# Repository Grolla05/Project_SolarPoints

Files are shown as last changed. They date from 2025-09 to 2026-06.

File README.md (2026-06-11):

# 💡 Project Solar Points — Smart Lighting for Low-Infrastructure Areas

> Light where there’s no infrastructure. Safety through simplicity and efficiency.



---

## 🌙 O que é o Solar Points?

O **Solar Points** é um sistema de iluminação pública autônomo e inteligente pensado para locais com pouca ou nenhuma infraestrutura elétrica, como:

- Paradas de ônibus
- Vielas e ruas estreitas
- Praças públicas
- Regiões periféricas e isoladas
- Áreas externas de residências

O objetivo permanece o mesmo: aumentar a segurança e o bem-estar comunitário com uma solução de baixo custo, sustentável e de fácil manutenção.

---

## 🔁 Evolução do projeto: de totalmente analógico para arquitetura digital

Inicialmente o projeto foi concebido como **100% analógico** (apenas componentes discretos e circuitos analógicos). Com as necessidades de sensoriamento mais preciso, flexibilidade operacional e otimização de consumo, o projeto evoluiu para uma **arquitetura digital/híbrida** baseada em microcontrolador e periféricos.

Essa mudança preserva os princípios de simplicidade, robustez e baixo consumo, ao mesmo tempo que agrega capacidades importantes:

- **Leitura digital de sensores** (intensidade de luz, distância/presença)
- **Decisões e temporizações programáveis** via firmware leve
- **Gerenciamento inteligente de energia** (controle de conversores DC-DC, modos de sono)
- **Comunicação entre módulos** via I2C/GPIO quando necessário

> A imagem anexada ao repositório ilustra o bloco funcional do novo design: microcontrolador central, sensores de luz e distância, gerenciamento de energia, baterias e conversores DC-DC.

---

## ⚙️ Principais funcionalidades (atualizado)

- **Ativação automática** baseada em sensores de luminosidade e presença
- **Modos ajustáveis** via firmware (p.ex. sensibilidades, temporização)
- **Operação autônoma** com painéis solares e baterias
- **Gestão adequada de energia** com conversores DC-DC e técnicas de baixo consumo
- **Projeto modular e replicável** com possibilidade de atualização de firmware

---

## 🛠️ Tecnologias e componentes (atualizado)

- **Microcontrolador** (unidade central de controle) — responsável por leitura de sensores e lógica de acionamento
- **Sensor de luminosidade** (LDR/photodiode + ADC) — medida de intensidade luminosa
- **Sensor de distância/presença** (ultrassom/IR) — detectar passagem ou presença
- **Conversores DC-DC** (step-up/step-down) — fornecimento estável para LEDs e eletrônica
- **Gestão de energia / Power Management** (monitoramento de bateria, carregamento solar)
- **Bateria recarregável e painéis solares**
- **LEDs de potência** para iluminação pública
- **Interfaces**: GPIOs para sinalização/controle, I2C para sensores/power ICs quando aplicável

---

## 🔍 Diagrama funcional

O diagrama no repositório mostra os blocos principais interconectados:

- 1 — Baterias (alimentação)
- 4 — Power Management (monitoramento/carregador)
- 11 — Conversão DC-DC (alimentação dos LEDs e eletrônica)
- 2 — Microcontrolador (núcleo lógico)
- 5 — Medição de intensidade luminosa (sensor)
- 6 — Sensor de distância/presença
- 3 — LED de status / power

O microcontrolador realiza a lógica central: lê sensores (GPIOs/ADC/I2C), decide quando ligar os LEDs e controla os conversores para otimizar consumo.

---

## ✨ Aplicações no mundo real

O Solar Points continua ideal para iluminar pontos sem infraestrutura elétrica: pontos de ônibus, caminhos em áreas rurais, entradas de condomínios e outras localidades onde uma solução autônoma e resiliente faz diferença.

---

## 👥 Autores

Desenvolvido por:

- **Felipe Grolla Freitas** – Engenharia de Controle e Automação (PUC-Campinas)
- **Guilherme Oliveira Nogueira** – Engenharia de Controle e Automação (PUC-Campinas)
- **Giovanna Lima Salvagnini** – Engenharia de Controle e Automação (PUC-Campinas)
- **Henrique Spadaccia Chambó** – Engenharia de Controle e Automação (PUC-Campinas)

---

> 🧠 "A simplicidade, aliada a decisões digitais pontuais, amplia o impacto das soluções de engenharia em contextos reais."

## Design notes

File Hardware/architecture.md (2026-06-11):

# Documentação de Hardware - Projeto de Iluminação Autônoma Solar

## Visão Geral do Projeto

Este projeto consiste em um sistema de iluminação autônoma e inteligente, projetado para operar com energia solar. Ele carrega uma bateria interna e acende uma lâmpada LED ao detectar movimento, mas apenas quando a luz ambiente estiver baixa. A arquitetura de hardware é dividida em blocos funcionais para garantir eficiência, segurança e robustez.

-----

## 1. Arquitetura do Circuito

O circuito é centrado em um chip de **Gerenciamento de Energia** (Power Management) que controla o fluxo entre as fontes de energia, a bateria e o sistema lógico. A principal característica do design é a separação entre o **circuito de controle de baixa tensão (5V)** e o **circuito de potência de alta tensão (12V)**, isolados por um Módulo Relé.

### Diagrama de Blocos do Circuito Completo

```
+------------------------------------------------------------------------------------------------------------------------------+
|                            Gerenciamento de Energia (Ex: BQ25881)                                                            |
|                                                                                                                              |
|   Entrada 12V (Vin) do Painel Solar        Saída ~12V (SYS) para o Sistema                                                   |
|              ▼                                            ▼                                                                  |
|       +------+--------------------------------------------+------------------------------------------------------------------+
|       |      |                                            |                                                                  |
|       |      | Carrega/Descarrega (BAT)                   |                                                                  |
|       |      |                                            |                                                                  |
|       ▼      ▼                                            ▼                                                                  |
|  +----------+----------+                        +-------------------------+                                                  |
|  |  Bateria 12V + BMS  |                        | Conversor DC-DC (5V)    |                                                  |
|  +---------------------+                        +-----------+-------------+                                                  |
|          ^                                                  |                                                                |
|          |                                                  | (Alimentação Lógica 5V e GND)                                  |
|          +--------------------------------------------------+-------------------------------+                                |
|                                                             |                               |                                |
|  (Circuito de Controle - 5V)                                ▼                               |                                |
|                                                  +--------------------+                     |                                |
|                     +----------------------------+  Microcontrolador  |                     |                                |
|                     |                            |      (ESP32)       |                     |                                |
|                     |                            +--+------+-------+--+                     |                                |
|                     |                               |      |       |                        |                                |
|                 Módulo GPS               (Sinal IN) |      |       | (Sinal OUT)            |                                |
|                                                     ▼      ▼       ▼                        |                                |
|                                                +----------+-+-+----------+       +-------------------+                       |
|                                                | Sensor PIR | |Sensor LDR|       | Módulo Relé 5V    |                       |
|                                                +------------+ +----------+       |                   |                       |
|                                                                                  | VCC | GND | IN    |                       |
|                                                                                  +--+----+-----------+                       |
|                                                                                  |  |    |                                   |
|                                                                                  |  |    |                                   |
| (Circuito de Potência - 12V, chaveado pelo Relé)                                 |  |    | (do pino GPIO)                    |
|                                                                                  |  |    |                                   |
|   +---------------------+                                                        |  +----+ (do GND)                          |
|   | Fonte de Energia    |                                                        +-------+ (do 5V)                           |
|   | (Bateria/SYS ~12V)  |                                                                |                                   |
|   +----------+----------+                                                                |                                   |
|              | (+)                                                                       |                                   |
|              |                                                                           |                                   |
|              +---------------------------------------------------------------------------+ (Terminal COM)                    |
|                                                                                             (Terminal NO)                    |
|                                                                                                   |                          |
|                                                                                                   | (+)                      |
|                                                                                                   ▼                          |
|                                                                                            +---------------+                 |
|                                                                                            | Lâmpada LED   |                 |
|                                                                                            |     12V       |                 |
|                                                                                            +-------+-------+                 |
|                                                                                                    | (-)                     |
|                                                                                                    ▼                         |
|                                                                                             (GND da Fonte 12V)               |
|                                                                                                                              |
+------------------------------------------------------------------------------------------------------------------------------+
```

-----

## 2. Seleção de Componentes e Justificativa

A escolha de cada componente foi pensada para garantir segurança, eficiência e funcionalidade.

* **Painel Solar (12V):** Fonte de energia primária. Sua tensão de 12V é ideal para carregar diretamente a bateria de 12V e alimentar o circuito lógico.
* **Bateria de Lítio (12V 3S):** Fornece energia para o sistema durante a noite. Uma bateria de 3 células em série (3S) tem tensão nominal de 11.1V, compatível com a fonte solar.
* **Módulo BMS (Battery Management System):** **Componente crítico para a segurança**. O BMS protege a bateria contra sobrecarga, sobredescarga e curtos-circuitos, além de realizar o balanceamento de células, prolongando a vida útil do pacote de baterias.
* **Chip de Gerenciamento de Energia (Ex: BQ25881):** O cérebro do sistema de energia. Este chip implementa a funcionalidade de ***power path***, direcionando a energia da fonte solar para a carga e, em seguida, para a bateria, de forma automática e eficiente.
* **Conversor DC-DC (Step-down):** Essencial para a eficiência. Ele recebe a tensão variável da saída do gerenciador de energia e a converte para uma tensão estável de 5V, ideal para o microcontrolador e os sensores. A alta eficiência minimiza a perda de energia em forma de calor.
* **Microcontrolador (ESP32):** O controlador lógico. O ESP32 foi escolhido por sua versatilidade, baixo consumo de energia e capacidade de processar dados dos sensores.
* **Sensor PIR (Infravermelho Passivo):** Sensor de movimento. Envia um sinal digital `HIGH` para o ESP32 quando detecta presença, ativando a rotina de acionamento da luz.
* **Sensor de Luz (LDR):** Sensor de luminosidade. Através de um divisor de tensão, ele fornece um sinal analógico ao ESP32, permitindo que o sistema determine se a luz ambiente é suficiente para ligar a lâmpada.
* **Módulo Relé 5V com Optoacoplador:** Atua como um interruptor eletrônico seguro. Permite que o ESP32, com um sinal de baixa potência (5V), controle uma carga de alta potência (a lâmpada de 12V). O **optoacoplador** é fundamental, pois isola eletricamente o microcontrolador do circuito de potência, protegendo-o de ruídos e picos de tensão gerados pelo acionamento do relé.

-----

## 3. Fluxo de Operação do Circuito

O sistema opera em um ciclo contínuo, com a energia e a lógica seguindo um fluxo bem definido:

1. **Gerenciamento de Energia:** A energia do painel solar entra no chip de gerenciamento (`Vin`), que a direciona para a saída `SYS` (para alimentar o sistema) e para a porta `BAT` (para carregar a bateria via BMS).

2. **Alimentação Lógica:** O conversor DC-DC recebe a energia da saída `SYS` e a regula para 5V, alimentando o **ESP32**, os sensores e o Módulo Relé de forma estável.

3. **Lógica Condicional:** O **ESP32** continuamente lê a saída dos dois sensores:
    * O sinal **digital** do **sensor PIR** (HIGH se houver movimento).
    * O sinal **analógico** do **sensor de luz**.

4. **Acionamento da Lâmpada:** O **ESP32** só envia um sinal de ativação para o Módulo Relé se **ambas** as condições forem verdadeiras:
    * `(1)` **Há movimento detectado** (sinal PIR = HIGH).
    * `(2)` **A luz ambiente é insuficiente** (o valor analógico do sensor de luz está acima de um limite programado).

5. **Controle via Relé:** Se as condições forem atendidas, o **ESP32** envia um sinal digital `HIGH` para o Módulo Relé. O relé então atua como um interruptor, fechando o circuito de 12V e acendendo a Lâmpada LED em sua potência máxima. Quando as condições não são mais atendidas, um sinal `LOW` é enviado, abrindo o circuito e desligando a lâmpada.

-----

## 4\. Lista de Materiais

* Painel Solar 12V
* Bateria de Lítio (3S, 12V)
* <a href="https://www.handsontec.com/dataspecs/module/3S-10A-18650-Charger.pdf">Módulo BMS 3S</a>
* <a href="https://www.ti.com/lit/ug/sluuc12/sluuc12.pdf?ts=1757377702366">Chip de Gerenciamento de Bateria com ***Power Path*** (ex: BQ25881)</a>
* Conversor DC-DC Step-down (para 5V)
* <a href="https://www.espressif.com/sites/default/files/documentation/esp32_datasheet_en.pdf">**Microcontrolador ESP32**</a>
* <a href="https://www.handsontec.com/dataspecs/SR501%20Motion%20Sensor.pdf">Sensor de Movimento PIR (HC-SR501)</a>
* <a href="https://components101.com/sites/default/files/component_datasheet/LDR%20Datasheet.pdf">Sensor de Luz (LDR)</a>
* <a href="https://www.eletruscomp.com.br/arquivos/1488539846_dados_tecnicos_p9___gbk_rele_10a_simples.pdf">Relay</a>
* Lampada LED
* <a href="https://content.u-blox.com/sites/default/files/products/documents/NEO-6_DataSheet_%28GPS.G6-HW-09005%29.pdf">Módulo GPS (NEO-6)</a>
* Resistores: 10kΩ, 1kΩ e 220Ω (ou 330Ω)

-----

## 5\. Esquemas e Layouts do Projeto

Esta seção é dedicada à documentação visual do projeto, fundamental para a construção e replicação.

### Diagrama Esquemático

* [Insira aqui a imagem do seu diagrama esquemático, mostrando as conexões de todos os componentes.]

### Layout da Placa de Circuito Impresso (PCB)

* [Insira aqui a imagem do layout da sua PCB, com as trilhas, componentes e silkscreen.]

### Imagens do Protótipo ou Produto Final

* [Insira aqui as fotos do seu projeto montado na protoboard ou na PCB final.]

-----

## 6\. Desenvolvedores do Projeto

**Felipe Grolla Freitas** – Engenharia de Controle e Automação (PUC-Campinas)<br>
**Guilherme Oliveira Nogueira** – Engenharia de Controle e Automação (PUC-Campinas)<br>
**Giovanna Lima Salvagnini** – Engenharia de Controle e Automação (PUC-Campinas)<br>
**Henrique Spadaccia Chambó** – Engenharia de Controle e Automação (PUC-Campinas)

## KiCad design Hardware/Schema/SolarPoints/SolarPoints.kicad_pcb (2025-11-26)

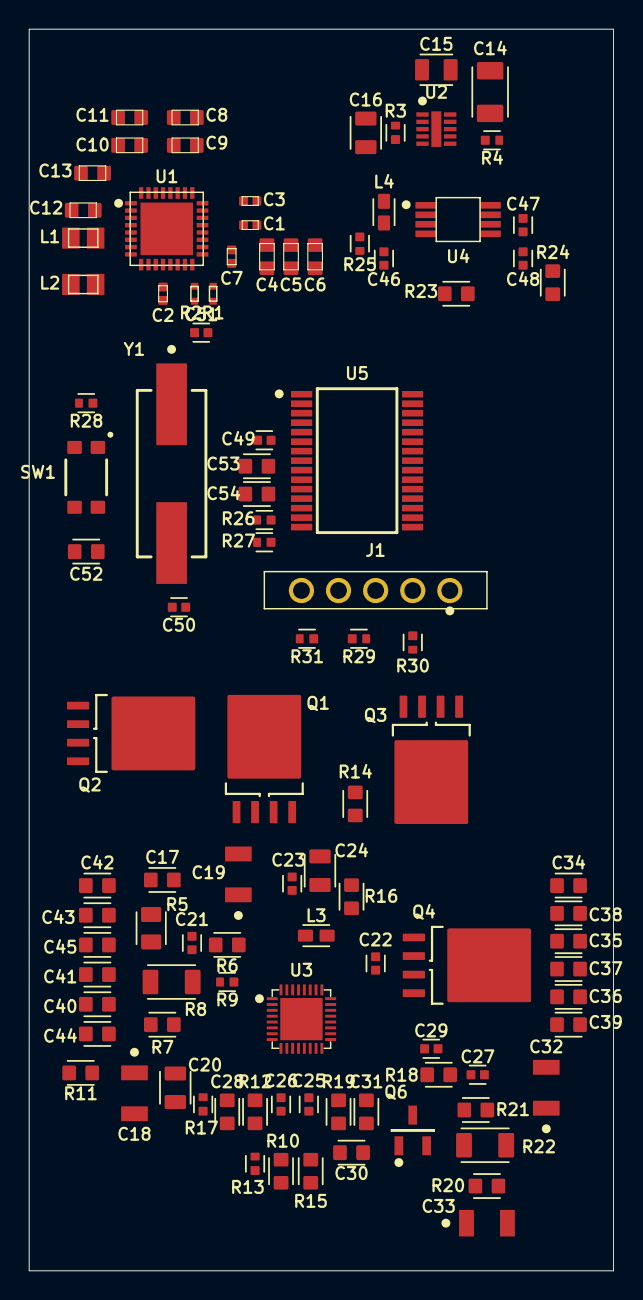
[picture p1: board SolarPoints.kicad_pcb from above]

Board: 0 copper layers, 40.0 x 85.0 mm, 102 parts (0 on the bottom side), 63 nets, no tracks yet.

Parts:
C1, C3: 04023D105KAT2A
C2: KGM05CR71H104KH
C4, C5, C6, C8, C9, C10, C11, C12, C13: GRM188Z71A106KA73D
C7: GRM155Z71A225KE01D
C14: 12061C105K4Z4A
C15: 08051C104KAT2A
C16, C20: 08051C474K4Z2A
C17, C28: CL10A105KL8NNNC
C18, C19, C32, C33: C1206C153J5GACTU
C21: GRM155R71E103KA01D
C22, C23: GRM155R71H473KE14J
C24: C0805C225K5RACTU
C25, C26: CL05C101JB51PND
C27: CL05B681KB5VPNC
C29: CC0402JRNPO9BN150
C30: CL10C182JB8NNNC
C31: GRM1885C1H330JA01D
C34, C35, C36, C37, C38, C39, C40, C41, C42, C43, C44, C45: CL10A106MA8NRNC
C46, C48: GRM155R60J106ME15D
C47: GRM158R61A226ME15D
C49: CL05A105KO5NNNC
C50, C51: C0402C180J5GACTU
C52, C53, C54: 06035C104K4T2A
J1: 61300511021
L1, L2: MLZ2012M2R2HT000
L3, L4: LQM18PN2R2MFRL
Q1, Q2, Q3, Q4: SIJA72ADP-T1-GE3
Q6: SI2319DS-T1-E3
R1: ERJ2RKF4702X
R2: ERJ2RKF1503X
R3: ERJ2BSFR10X
R4: ERJ2RKF2001X
R5: CRCW08052R20FKEA
R6, R7, R16, R20, R21: RC0603FR-0710RL
R8, R22: ERJ8CWFR010V
R9: ERJ2GEJ1R0X
R10: ERJ3EKF3002V
R11: ERJ3EKF1003V
R12: RT0603FRE13330KL
R13, R17: ERJ2RKF2203X
R14: ERJ3GEYJ103V
R15: RT0603BRE0750RL
R18: ERJ3EKF1002V
R19: ERJS03F4022V
R23: ERJPA3F1003V
R24: ERJ3EKF7503V
R25: ERA2AED472X
R26, R27, R28: MCS0402MC1002FE000
R29, R30, R31: ERJ2RKF1001X
SW1: KMR221GLFS
U1: NPM1300-QEAA-R
U2: LTC2959IDDB#TRMPBF
U3: BQ25708RSNR
U4: PAM2401SCADJ
U5: R5F102AAASP#50
Y1: ABLS-20.000MHZ-B-2-T

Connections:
/GPIO4: R14.1, U1.11, U3.4
/sheet_1_Power Management/VBUSOUT: C3.1, U1.22
/sheet_2_Batteries/GPIO: R4.1, U2.8
/sheet_3_Battery Managemen.../ACN: C19.1, R6.1, U3.2
/sheet_3_Battery Managemen.../ACP: C18.1, R7.1, U3.3
/sheet_3_Battery Managemen.../BATDRV: Q6.1, U3.21
/sheet_3_Battery Managemen.../HIDRV1: Q1.4, U3.31
/sheet_3_Battery Managemen.../HIDRV2: Q4.4, U3.24
/sheet_3_Battery Managemen.../LODRV1: Q2.4, U3.29
/sheet_3_Battery Managemen.../LODRV2: Q3.4, U3.26
/sheet_3_Battery Managemen.../N$1_1: C28.1, R17.2, U3.6
/sheet_3_Battery Managemen.../PROCHOT: R15.2, U3.11
/sheet_3_Battery Managemen.../REGN: C24.1, R16.1, U3.28
/sheet_3_Battery Managemen.../SRN: C33.1, R20.1, U3.19
/sheet_3_Battery Managemen.../SRP: C32.1, R21.1, U3.20
/sheet_3_Battery Managemen.../SW1: C23.1, L3.1, Q1.1, Q1.2, Q1.3, Q2.5, U3.32
/sheet_3_Battery Managemen.../SW2: C22.2, L3.2, Q3.5, Q4.1, Q4.2, Q4.3, U3.23
/sheet_3_Battery Managemen.../VBUS: C20.1, R9.1, U3.1
/sheet_3_Battery Managemen.../VDDA: R12.2, R16.2, U3.7
/sheet_4_Switching DC-DC C.../EN: R25.1, U4.2
/sheet_5_Microcontroller/RESET: C52.1, J1.4, R28.1, R29.1, R31.1, SW1.1, SW1.4, U5.6
/sheet_5_Microcontroller/SCL: R26.1, U5.13
/sheet_5_Microcontroller/SDA: R27.1, U5.14
/sheet_5_Microcontroller/TOOL0: J1.2, R30.1, U5.5
GND: C1.2, C2.2, C3.2, C4.2, C5.2, C6.2, C7.2, C8.2, C9.2, C10.2, C11.2, C12.2, C13.2, C14.2, C15.2, C17.2, C18.2, C19.2, C20.2, C21.2, C24.2, C25.2, C26.2, C27.2, C28.2, C29.2, C30.2, C31.2, C32.2, C33.2, C34.2, C35.2, C36.2, C37.2, C38.2, C39.2, C40.2, C41.2, C42.2, C43.2, C44.2, C45.2, C46.2, C47.2, C49.1, C50.2, C51.2, C52.2, C53.2, C54.2, J1.1, Q2.1, Q2.2, Q2.3, Q3.1, Q3.2, Q3.3, R1.1, R2.1, R10.1, R11.1, R13.1, R17.1, R23.1, SW1.2, SW1.3, U1.2, U1.6, U1.33, U2.10, U2.11, U3.14, U3.27, U3.33, U4.4, U4.8, U5.11
unnamed: C17.1, R5.1
unnamed: C27.1, R18.1
unnamed: C30.1, R19.1
unnamed: J1.3, R29.2
unnamed: L4.2, U4.1
unnamed: C21.1, Q1.5, R6.2, R8.1, R9.2
unnamed: Q6.2, R21.2, R22.2
unnamed: L1.1, U1.3
unnamed: L2.1, U1.5
unnamed: R1.2, U1.17
unnamed: R2.2, U1.16
unnamed: C16.2, U2.4
unnamed: C16.1, U2.3
unnamed: C14.1, U2.9
unnamed: C23.2, U3.30
unnamed: C22.1, U3.25
unnamed: R12.1, R13.2, U3.18
unnamed: C31.1, R19.2, U3.16
unnamed: C29.1, R18.2, U3.17
unnamed: C26.1, R11.2, U3.8
unnamed: C25.1, U3.9
unnamed: R10.2, U3.10
unnamed: C48.2, R23.2, R24.1, U4.5
unnamed: C50.1, U5.9, Y1.2
unnamed: C51.1, U5.8, Y1.1
VBAT: C7.1, C47.1, C48.1, R24.2, U1.19, U4.7
VBAT_1: R3.1, R20.2, R22.1, U2.5
VBUS_1: C1.1, U1.21
VCC: C53.1, C54.1, J1.5, R26.2, R27.2, R28.2, R30.2, R31.2, U5.12
VCC_1: C15.1, R3.2, U2.1, U2.2
VIN: C40.1, C41.1, C42.1, C43.1, C44.1, C45.1, R5.2, R7.2, R8.2
VOUT1: C2.1, C12.1, L1.2, U1.1, U1.12
VOUT2: C13.1, L2.2, U1.32
VOUTLDO1: C8.1, C9.1, U1.29
VOUTLDO2: C10.1, C11.1, U1.31
VREG: C46.1, C49.2, L4.1, R25.2, U4.3, U5.10
VSYS: C34.1, C35.1, C36.1, C37.1, C38.1, C39.1, Q4.5, Q6.3, R4.2, U3.22
VSYS_1: C4.1, C5.1, C6.1, U1.4, U1.20, U1.28, U1.30

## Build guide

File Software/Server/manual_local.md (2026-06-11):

# Manual de Execução do Sistema Solar Points Localmente

Este manual fornece um guia passo a passo para configurar e executar os servidores de back-end e front-end do sistema Solar Points, além de demonstrar como simular o envio de dados usando o Postman.

### 1. Configuração Inicial

Antes de executar os servidores, garanta que você tenha o Python e as bibliotecas necessárias instaladas.

1. **Instalar Flask:** Abra o terminal e instale a biblioteca Flask.
    ```bash
    pip install Flask
    ```
2. **Organizar os Arquivos:** Certifique-se de que os seus arquivos estejam organizados nas seguintes pastas, conforme a estrutura do projeto:
    * `Back-end/main.py`
    * `Front-end/app.py`
    * `Front-end/templates/` (com `index.html` e `layout.html`)
    * `Front-end/static/` (com `Maps_API.js` e `global.css`)
    * `database/` (pasta que será criada automaticamente)

### 2. Executando o Servidor de Back-end

O servidor de back-end (`main.py`) é responsável por receber os dados enviados pelo ESP32 e salvá-los no banco de dados.

1. Abra um terminal e navegue até a pasta `Back-end`.
2. Execute o servidor com o seguinte comando:

    ```bash
    python main.py
    ```

3. Você verá uma mensagem no terminal indicando que o servidor está rodando. Por padrão, ele será executado na porta **3000**.

    ```terminal
    * Running on [http://0.0.0.0:3000/](http://0.0.0.0:3000/)
    ```

### 3. Executando o Servidor de Front-end

O servidor de front-end (`app.py`) é responsável por consultar os dados do banco e exibi-los em uma página web com o mapa.

1. Abra um **segundo terminal** e navegue até a pasta `Front-end`.
2. Execute o servidor com o seguinte comando:

    ```bash
    python app.py
    ```

3. Você verá uma mensagem no terminal indicando que o servidor está rodando. Por padrão, ele será executado na porta **5000**.

    ```terminal
    * Running on [http://127.0.0.1:5000/](http://127.0.0.1:5000/)
    ```

4. Abra seu navegador e acesse o endereço `http://localhost:5000` para ver a interface do mapa.

### 4. Simulação de Dados com Postman

Com os dois servidores rodando, você pode usar o Postman para simular o envio de dados do ESP32 para o back-end.

1. Abra o Postman e crie uma nova requisição.
2. Defina o método da requisição como **`POST`**.
3. No campo de URL, insira o endereço do seu servidor de back-end: `http://localhost:3000/Back-end`.
4. Vá para a aba **`Body`**, selecione a opção **`raw`** e escolha **`JSON`** no menu suspenso.
5. Insira o seguinte JSON no corpo da requisição:
    ```json
    {
      "Dado1": 150,
      "localizacao": {
        "latitude": -23.57,
        "longitude": -46.79
      }
    }
    ```
    * Você pode alterar os valores de `Dado1`, `latitude` e `longitude` para simular diferentes envios. Se você enviar dados com a mesma latitude e longitude, o valor de `Dado1` será somado.

6. Clique no botão **`Send`**.

### Verificação

* **No Postman:** Você deverá receber uma resposta com status **`200 OK`** e a mensagem `"Dados recebidos e processados com sucesso!"`.
* **No terminal do Back-end (`main.py`):** Você verá as mensagens de log confirmando que os dados foram recebidos e salvos (ou atualizados) no banco de dados.
* **No navegador (Front-end):** Atualize a página e você verá o novo ponto de dados aparecer no mapa.

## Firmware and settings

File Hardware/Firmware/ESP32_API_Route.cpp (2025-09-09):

/**
 * @file ESP32_Controle_Final_Com_API_e_GPS.cpp
 * @brief Código de controle para sistema de iluminação autônoma com ESP32.
 * * Este programa lê um sensor de movimento (PIR), um sensor de luz (LDR) e um módulo GPS.
 * Se o movimento for detectado E o ambiente estiver escuro, ele aciona um Módulo Relé.
 * * QUANDO a contagem de movimentos atingir 10, os dados (contagem e coordenadas GPS) 
 * são enviados para uma API via requisição POST.
 * * * Conexões de Hardware:
 * - Sensor PIR      -> GPIO 2
 * - Sensor LDR      -> GPIO 34
 * - Módulo Relé     -> GPIO 19
 * - GPS Module TX   -> ESP32 RX (GPIO 16)
 * - GPS Module RX   -> ESP32 TX (GPIO 17)
 */

// --- Bibliotecas Adicionadas para Wi-Fi, HTTP e GPS ---
#include <WiFi.h>
#include <HTTPClient.h>
#include <TinyGPS++.h>
#include <HardwareSerial.h>
#include <WiFiClientSecure.h>

// --- Configurações Adicionadas para o Módulo GPS ---
static const int GPS_RX_PIN = 16;                                                       // Pino GPIO para receber dados do GPS (conectar ao TX do GPS)
static const int GPS_TX_PIN = 17;                                                       // Pino GPIO para transmitir dados para o GPS (conectar ao RX do GPS)
static const uint32_t GPS_BAUD = 9600;                                                  // Baud rate padrão para a maioria dos módulos GPS
TinyGPSPlus gps;                                                                        // Cria um objeto da biblioteca TinyGPS++
HardwareSerial ss(1);                                                                   // Usa a Serial1 do ESP32 para comunicação com o GPS
double latitudeGlobal = 0.0;
double longitudeGlobal = 0.0;

// --- Credenciais de Rede e API ---
WiFiClientSecure wifiClientSecure;
const char* ssid = "NOME_DA_SUA_REDE_WIFI";                                             // Nome da rede Wi-fi no qual o ESP32 irá se conectar
const char* password = "SENHA_DA_SUA_REDE_WIFI";                                        // Senha da rede Wi-fi no qual o ESP32 irá se conectar
const char* apiUrl = "https://solarpointsback.vercel.app/receber-dados-esp";            // Endpoint da API para onde os dados serão enviados (Servidor Back-end)

// --- MAPEAMENTO DOS PINOS DE HARDWARE E VARIÁVEIS GLOBAIS E DE CONTROLE ---
const int pinoPIR = 2;                                                                  // Pino de sinal do sensor de movimento (PIR)
const int pinoLDR = 34;                                                                 // Pino de sinal do sensor de luz (LDR) - Deve ser um pino ADC
const int pinoRele = 19;                                                                // Pino que envia o sinal de controle para o Módulo Relé
bool movimentoDetectado = false;                                                        // "Trava" para garantir que o contador de movimento incremente apenas uma vez por evento
bool releEstaLigado = false;                                                            // Flag para otimizar a impressão no Monitor Serial, mostrando o estado apenas quando ele muda
int contadorMovimento = 0;                                                              // Contador para registrar o número de vezes que o movimento foi detectado

//================================================================================
// FUNÇÃO: PARA OBTER DADOS DO GPS
//================================================================================
void obterCoordenadasGPS(unsigned long timeout) {                                       // Função para obter as coordenadas GPS
  Serial.println("Tentando obter coordenadas do GPS...");
  unsigned long start = millis();                                                       // Marca o tempo de início

  bool gotFix = false;
  do {                                                                                  // Loop até obter um sinal válido ou até 1 segundo se passar
    while (ss.available() > 0) {                                                        // Lê os dados do GPS
      if (gps.encode(ss.read())) {                                                      // Decodifica os dados do GPS
        if (gps.location.isValid() && gps.location.isUpdated()) {                       // Verifica se a localização é válida e foi atualizada
          latitudeGlobal = gps.location.lat();                                          // Atualiza a latitude global
          longitudeGlobal = gps.location.lng();                                         // Atualiza a longitude global
          gotFix = true;
          break;                                                                        // sai do while(ss.available...) assim que tiver um fix atualizado
        }
      }
    }
    if (gotFix) break;                                                                  // sai do do-while se obteve fix
    delay(50);                                                                          // evita busy-loop intenso
  } while (millis() - start < 1000);                                                    // Continua o loop por até 1 segundo

  if (latitudeGlobal != 0.0) {                                                          // Verifica se uma coordenada válida foi obtida
      Serial.print("Coordenadas obtidas: ");
      Serial.print("Latitude= "); Serial.print(latitudeGlobal, 6);                      // Imprime a latitude com 6 casas decimais
      Serial.print(" Longitude= "); Serial.println(longitudeGlobal, 6);                 // Imprime a longitude com 6 casas decimais
  } else {
    Serial.println("Ainda nao foi possivel obter um sinal de GPS valido.");
  }
}

//================================================================================
// FUNÇÃO ENVIO DE DADOS (REQUISIÇÃO HTTP POST PARA A API)
//================================================================================
void envioDeDados() {
  if (WiFi.status() == WL_CONNECTED) {                                                  // Verifica se o ESP32 está conectado ao Wi-Fi
    HTTPClient http;
    Serial.println("Iniciando envio de dados para a API...");
    int contadorParaEnviar = contadorMovimento;                                         // Captura local do contador para evitar que ele seja alterado por outro trecho do código durante o envio
    obterCoordenadasGPS(2000);                                                          // Chama a função para obter as coordenadas GPS
    String url(apiUrl);                                                                 // Escolhe cliente adequado conforme protocolo (HTTP vs HTTPS)
    WiFiClient wifiClient;
    WiFiClientSecure wifiClientSecure;
    if (url.startsWith("https://")) {
      wifiClientSecure.setInsecure();                                                   // CUIDADO: setInsecure() desativa verificação TLS — ok para desenvolvimento/testes, em produção prefira validar o certificado ou usar certificate pinning.
      http.begin(wifiClientSecure, url);
    } else {
      http.begin(wifiClient, url);
    }
    http.addHeader("Content-Type", "application/json");                                 // Define o cabeçalho para indicar que estamos enviando dados em formato JSON
    String jsonPayload = "{\"Contador\":" + String(contadorParaEnviar) +                // Cria o corpo (payload) da requisição em formato JSON exatamente no formato exigido
                         ",\"localizacao\":{\"latitude\":" + String(latitudeGlobal, 6) +
                         ",\"longitude\":" + String(longitudeGlobal, 6) + "}}";

    Serial.print("Payload a ser enviado: ");
    Serial.println(jsonPayload);                                                        // Exibe o payload no Monitor Serial para verificação
    int httpResponseCode = http.POST(jsonPayload);                                      // Envia a requisição POST e obtém o código de resposta do servidor
    if (httpResponseCode > 0) {
      Serial.print("Requisicao POST enviada. Codigo de resposta: ");
      Serial.println(httpResponseCode);
      String response = http.getString();                                               // Pega a resposta do servidor
      Serial.print("Resposta do servidor: ");
      Serial.println(response);
    } else {
      Serial.print("Falha ao enviar requisicao POST. Codigo de erro: ");
      Serial.println(httpResponseCode);
    }
    http.end();                                                                         // Libera os recursos do cliente HTTP
  } else {
    Serial.println("ERRO: Nao foi possivel enviar os dados. ESP32 desconectado");
  }
}

//================================================================================
// FUNÇÃO SETUP: Executada uma única vez quando o ESP32 é ligado
//================================================================================
void setup() {
  Serial.begin(115200);                                                                 // 1. Inicia a comunicação serial para permitir o envio de mensagens de status (debug)
  ss.begin(GPS_BAUD, SERIAL_8N1, GPS_RX_PIN, GPS_TX_PIN);                               // Inicia a Serial1 para comunicação com o GPS  
  Serial.println("Inicializando comunicacao com o Modulo GPS...");                      // Mensagem de status com o Módulo GPS
  Serial.print("Conectando a rede Wi-Fi: ");
  Serial.println(ssid);                                                                 // Mensagem de status com a rede Wi-Fi                  
  WiFi.begin(ssid, password);                                                           // Inicia a conexão Wi-Fi       
  while (WiFi.status() != WL_CONNECTED) {                                               // Aguarda até que a conexão seja estabelecida     
    delay(500);
    Serial.print(".");
  }
  Serial.println("\nWi-Fi Conectado!");                                                 // Mensagem de status
  Serial.print("Endereco IP: ");
  Serial.println(WiFi.localIP());                                                       // Exibe o endereço IP atribuído ao ESP32
  pinMode(pinoPIR, INPUT);                                                              // 2. Configura os pinos dos sensores como ENTRADA (INPUT)
  pinMode(pinoRele, OUTPUT);                                                            // 3. Configura o pino do relé como SAÍDA (OUTPUT)
  digitalWrite(pinoRele, LOW);                                                          // 4. Garante que o relé (e a lâmpada) comece no estado DESLIGADO
  analogReadResolution(12);                                                             // 5. Define a resolução da leitura analógica para 12 bits (valores de 0 a 4095)
  Serial.println("\n>>> Sistema de Iluminacao Autonoma com Rele INICIADO <<<");
  Serial.println("Aguardando condicoes para acionar a lampada...");
}


//================================================================================
// FUNÇÃO LOOP: Executada repetidamente em um ciclo infinito
//================================================================================
void loop() {
  int estadoPIR = digitalRead(pinoPIR);                                                 // ETAPA 1: Ler o estado do sensor de movimento
  if (estadoPIR == HIGH) {                                                              // ETAPA 2: Lógica para contar o movimento apenas na "borda de subida" do sinal
    if (!movimentoDetectado) {
      movimentoDetectado = true;                                                        // Ativa a "trava"
      contadorMovimento++;
      Serial.print("EVENTO: Movimento detectado! Contagem total: ");
      Serial.println(contadorMovimento);
      if (contadorMovimento >= 10) {
        Serial.println("Preparando para enviar dados...");
        envioDeDados(contadorMovimento, latitudeGlobal, longitudeGlobal);               // Chama a função para enviar os dados via API
        contadorMovimento = 0;                                                          // Zera o contador para iniciar uma nova contagem
        Serial.println("Contador de movimento zerado.");
      }
    }
  } else {
    movimentoDetectado = false;                                                         // Libera a "trava" quando não há mais movimento
  }
  
  int valorLDR = analogRead(pinoLDR);                                                   // ETAPA 3: Ler o valor do sensor de luz (LDR)
  const int limiteEscuridao = 1500;                                                     // ETAPA 4: Definir o limite de escuridão
  
  if (movimentoDetectado && (valorLDR > limiteEscuridao)) {                             // ETAPA 5: Lógica principal de decisão
    digitalWrite(pinoRele, HIGH);                                                       // Liga a lâmpada
    if (!releEstaLigado) {
      Serial.println("STATUS: Condicoes atendidas -> Rele ACIONADO");
      releEstaLigado = true;
    }

  } else {
    digitalWrite(pinoRele, LOW);                                                        // Desliga a lâmpada
    if (releEstaLigado) {
      Serial.println("STATUS: Condicoes nao atendidas -> Rele DESLIGADO");
      releEstaLigado = false;
    }
  }
  delay(250);                                                                           // Pequena pausa para estabilidade do loop
}

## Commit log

2025-05-11 Update the finally circuit
    [SolarPoints.brd, SolarPoints.sch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]
2025-05-13 update files
    [SolarPoints.sch]
2025-05-19 update test
    [SolarPoints.sch]
2025-06-03 update feat
    [SolarPoints.brd, SolarPoints.sch, Solar_Points.brd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]
